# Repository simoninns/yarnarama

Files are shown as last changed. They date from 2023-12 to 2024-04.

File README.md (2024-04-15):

# Yarnarama - A yarn holder for knitting
## Overview
Yaranarama is a yarn holder for the discerning knitting engineer.  It features a fully bearing supported wool spindle mounted on a weighted based, as well as a built-in yarn guide.

This project is GPLv3 open-source and was designed with the assistance my daughter who is an enthusiastic knitter.

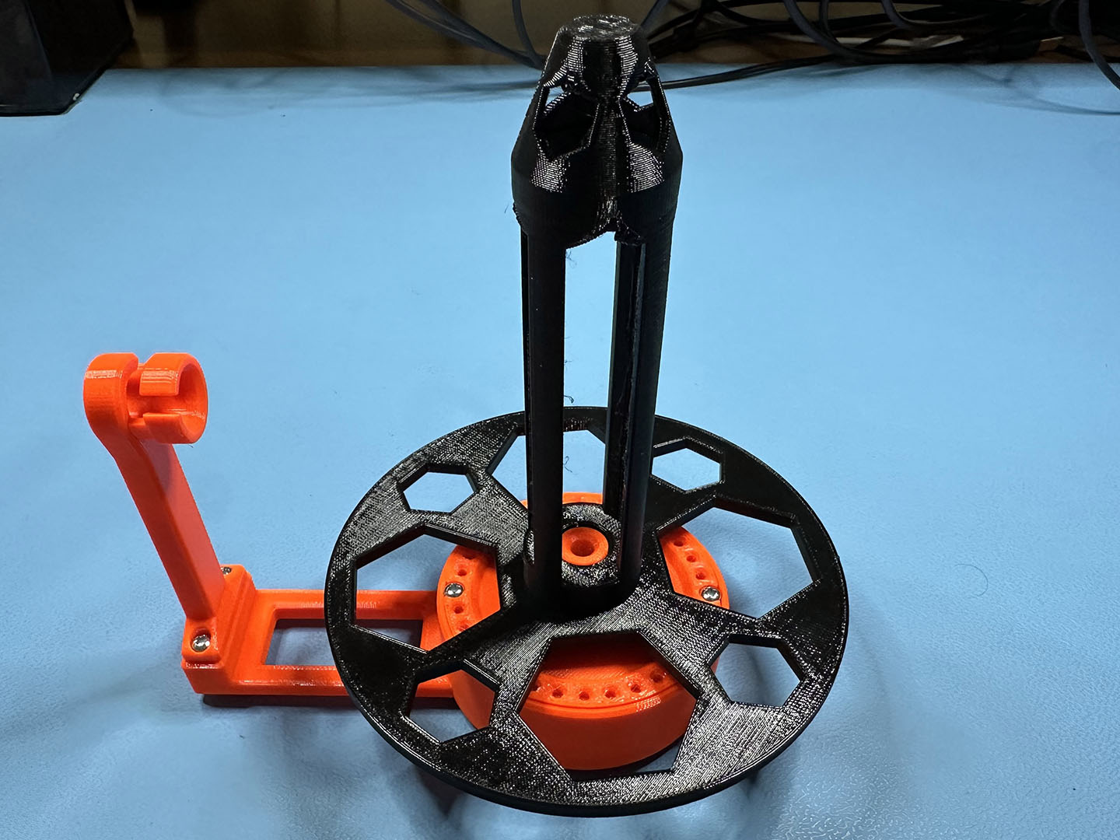
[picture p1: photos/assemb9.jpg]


## Printing instructions
The model has been printed and tested on the Prusa MK3S/MMU2S printer using Prusament PETG filament. All parts fit the standard print bed.

You will need:

* 5x M3x5.7 threaded inserts (heat-set)
* 5x M3x10mm screws
* 1x 608-2Z ball bearing
* 5x M20 washers (DIN9021 - id=22, od=60, h=3.5).
* 5x 13mm stick-on feet

When mounting the washers in the base it is advisable to pad any gap at the top of the bearings to stop them moving around.  Some foam tape or small bits of loose foam will work well.

### Recommended print settings

Print settings (for Prusa Slicer) are the same for all included parts:

* Material: PETG
* Layer: 0.30mm (Draft)
* Infill: 25%
* No supports required

Note: 0.30mm is used for fast print speed.  You can also use 0.20mm (Quality) if you like smoother looking prints.

## Assembly

Print all the parts.  Note that there are two types of shafts included, the standard diameter and a narrow shaft (to allow the yarn to relax slightly more).

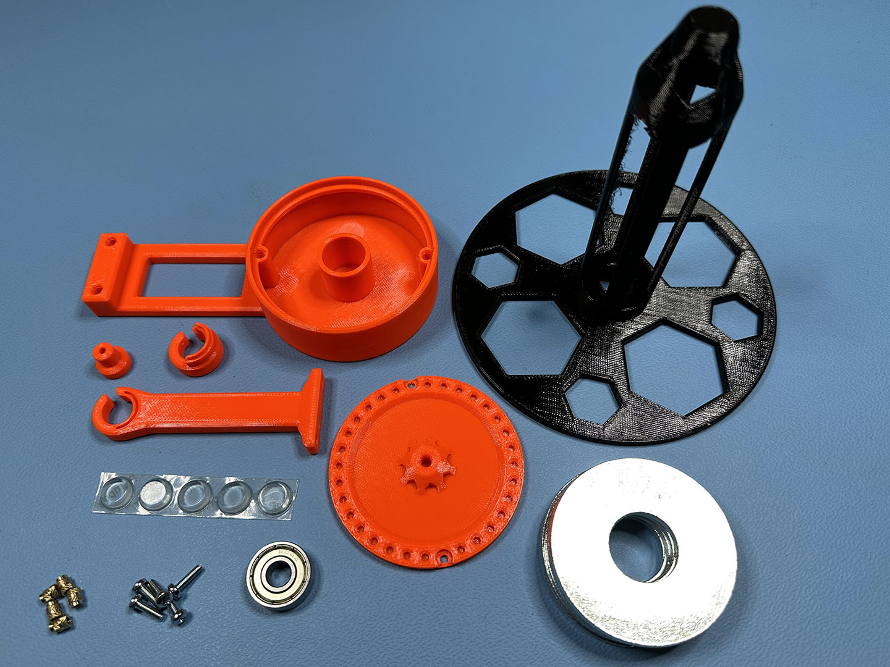
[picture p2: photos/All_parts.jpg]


Insert the heat set inserts in the base (4x) and spool base (1x).

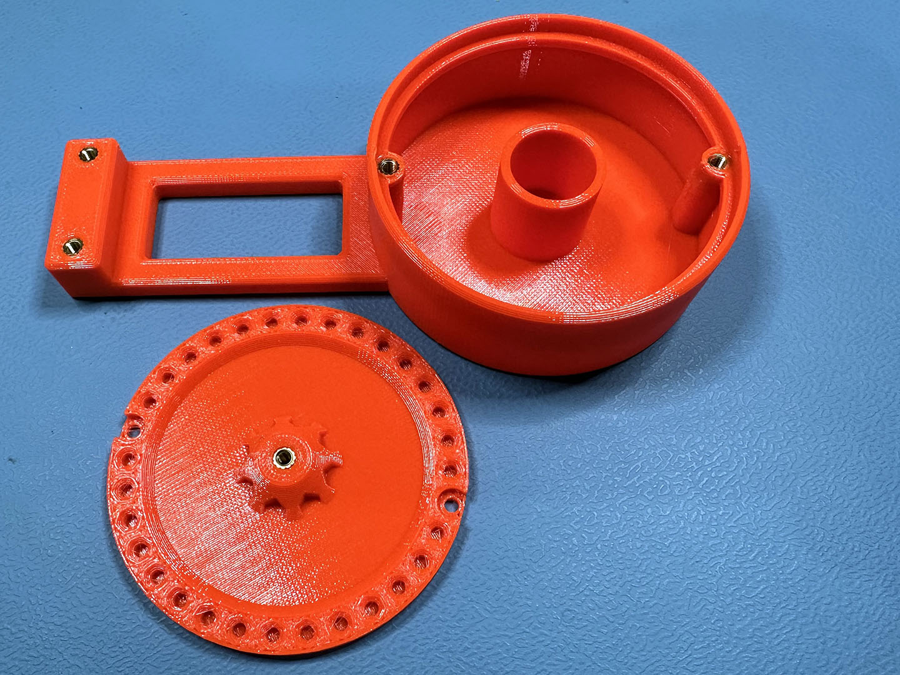
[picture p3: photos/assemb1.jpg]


Stick the 5 13mm feet to the base of the Yarnarama

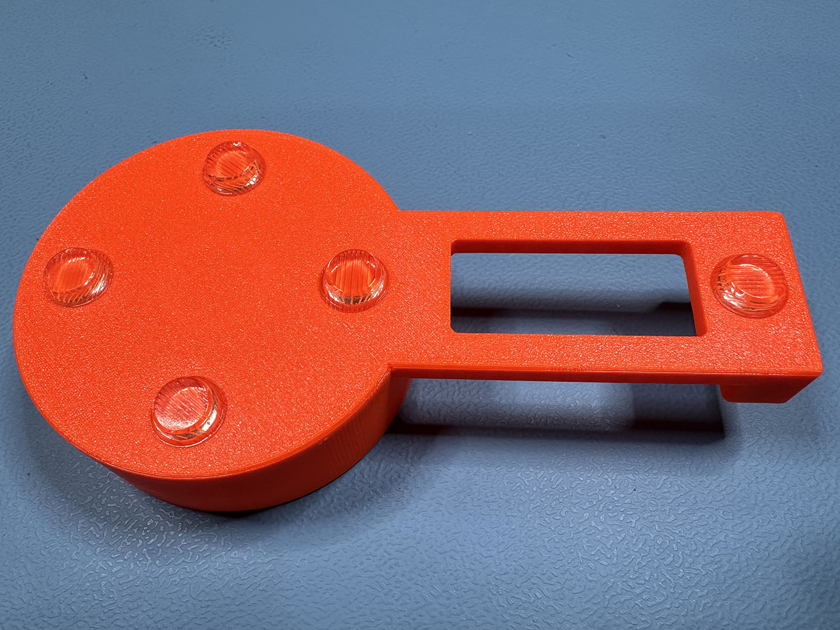
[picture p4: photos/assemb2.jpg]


Place 5 washers into the base, add some foam to the top washer to stop it moving when assembled.

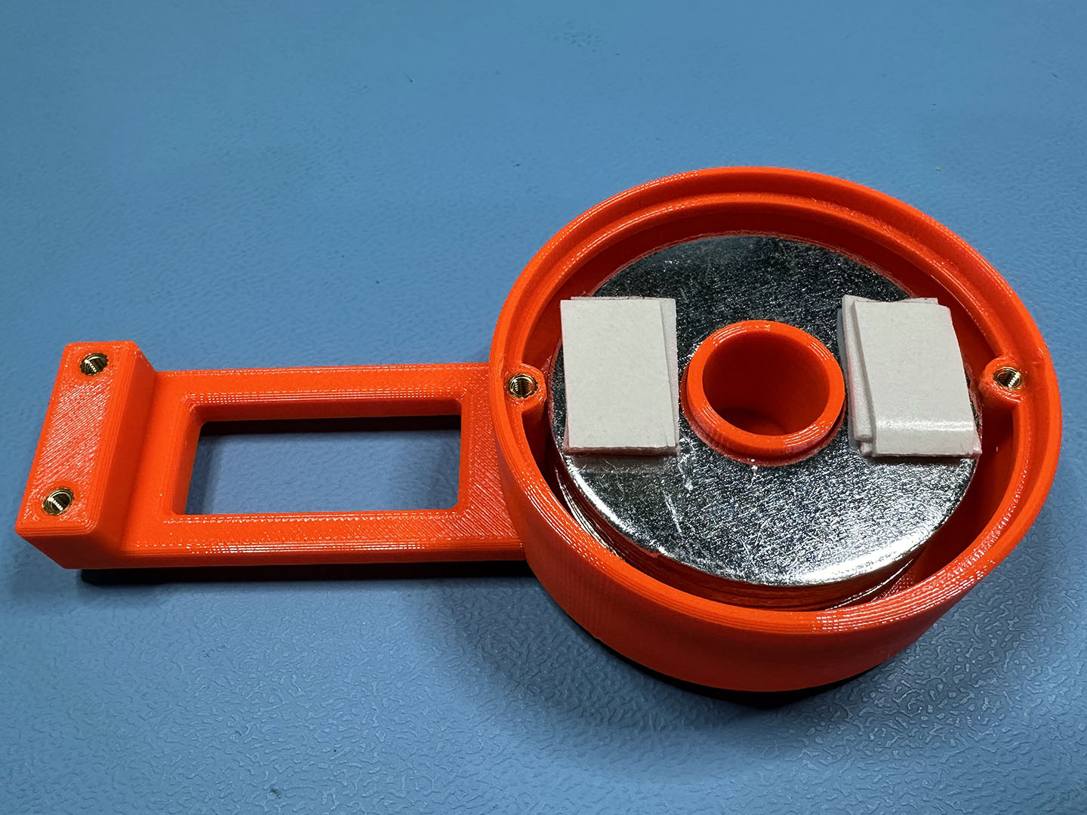
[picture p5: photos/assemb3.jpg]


Screw the spool base into place using 2x M3x10mm screws and put 1x M3x10mm screw into the spool holder

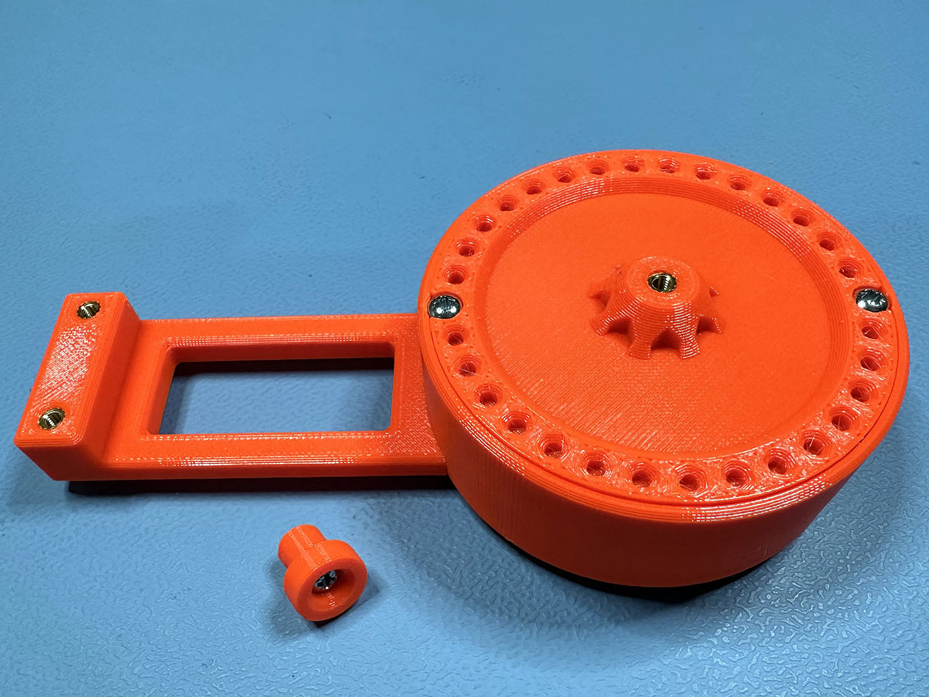
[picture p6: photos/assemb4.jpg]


Glue the guide rail into the provided slot of the guide (using a small amount of superglue)

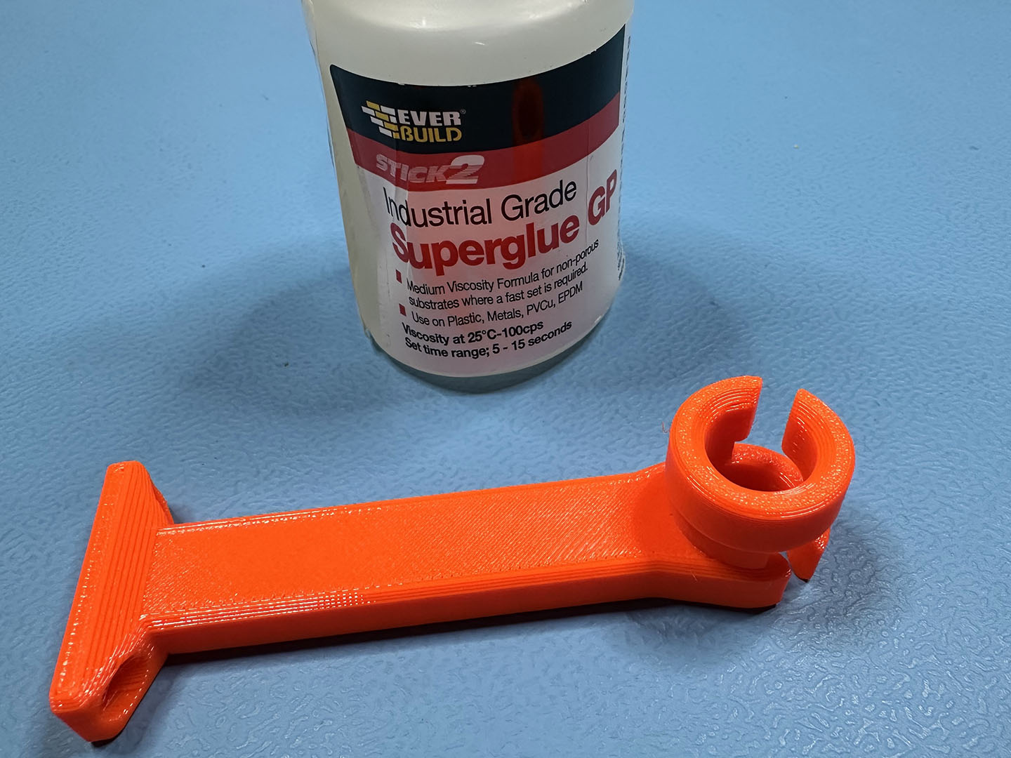
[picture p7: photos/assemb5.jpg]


Screw the guide into the base using 2x M3x10mm screws.

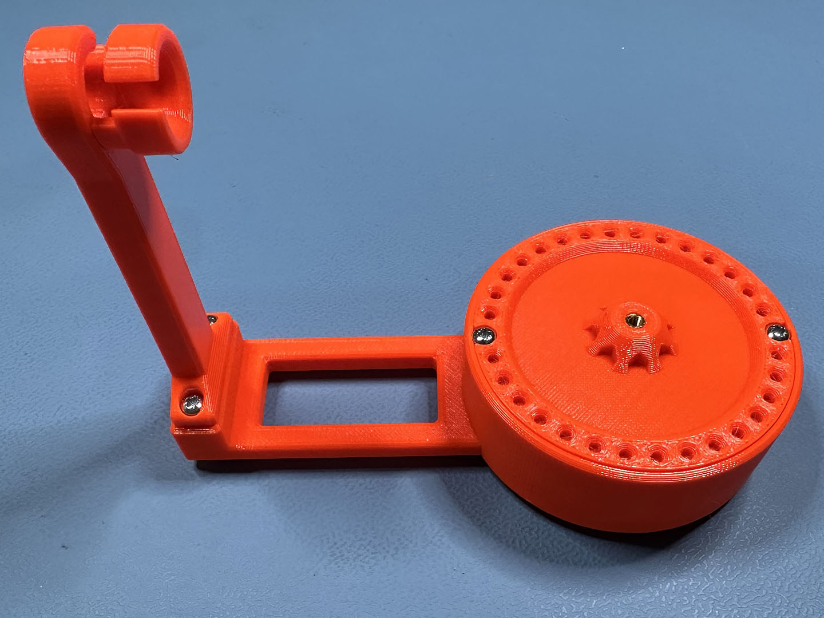
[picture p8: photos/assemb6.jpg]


Push the spool holder through the bearing

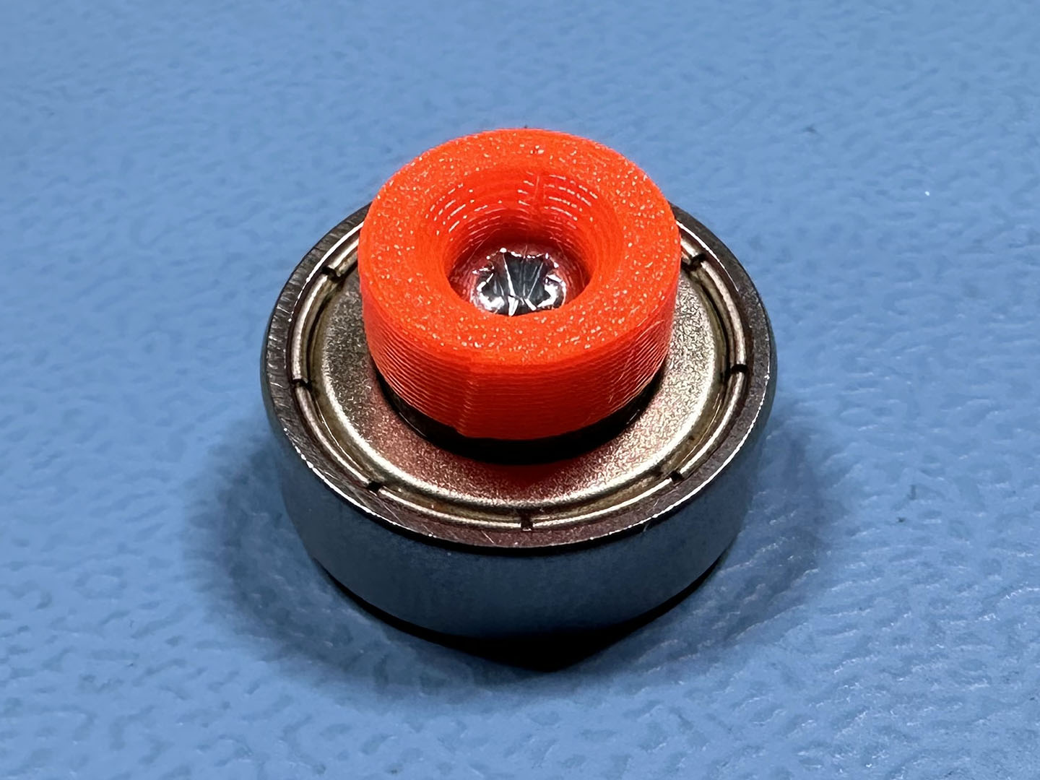
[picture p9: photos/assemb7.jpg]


Push the bearing into the base of the spool shaft

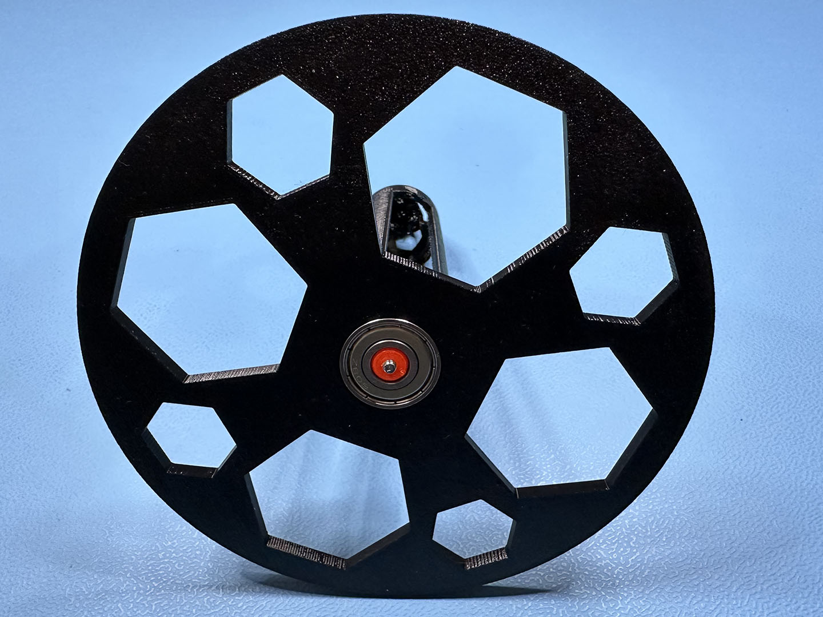
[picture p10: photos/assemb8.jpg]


Place the spool shaft onto the spool base and screw into place using the central M3x10mm screw (in the bearing holder)



## Author
The Yanarama is designed and maintained by Simon Inns.

## Cloning notes
This repo contains the BOSL OpenSCAD library as a sub-module, after you clone this repo use the following command to initialise the sub-modules:

git submodule update --init

# Licensing
## OpenSCAD source files - software license (GPLv3)

    This is free software: you can redistribute it and/or modify
    it under the terms of the GNU General Public License as published by
    the Free Software Foundation, either version 3 of the License, or
    (at your option) any later version.
    
    This program is distributed in the hope that it will be useful,
    but WITHOUT ANY WARRANTY; without even the implied warranty of
    MERCHANTABILITY or FITNESS FOR A PARTICULAR PURPOSE.  See the
    GNU General Public License for more details.
    
    You should have received a copy of the GNU General Public License
    along with this program.  If not, see <http://www.gnu.org/licenses/>.

## Non-source-code media - Creative Commons license (Creative Commons BY-SA 4.0)
Please see the following link for details: https://creativecommons.org/licenses/by-sa/4.0/

You are free to:

Share - copy and redistribute the material in any medium or format
Adapt - remix, transform, and build upon the material
for any purpose, even commercially.

This license is acceptable for Free Cultural Works.

The licensor cannot revoke these freedoms as long as you follow the license terms.

Under the following terms:

Attribution - You must give appropriate credit, provide a link to the license, and indicate if changes were made. You may do so in any reasonable manner, but not in any way that suggests the licensor endorses you or your use.

ShareAlike - If you remix, transform, or build upon the material, you must distribute your contributions under the same license as the original.

No additional restrictions - You may not apply legal terms or technological measures that legally restrict others from doing anything the license permits.

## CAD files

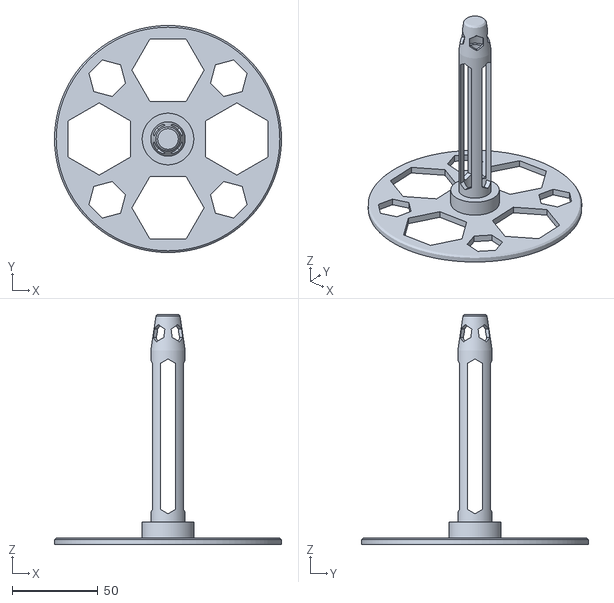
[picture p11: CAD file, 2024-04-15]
stl/spool_shaft_narrow.stl
132.0 x 132.0 x 134.0

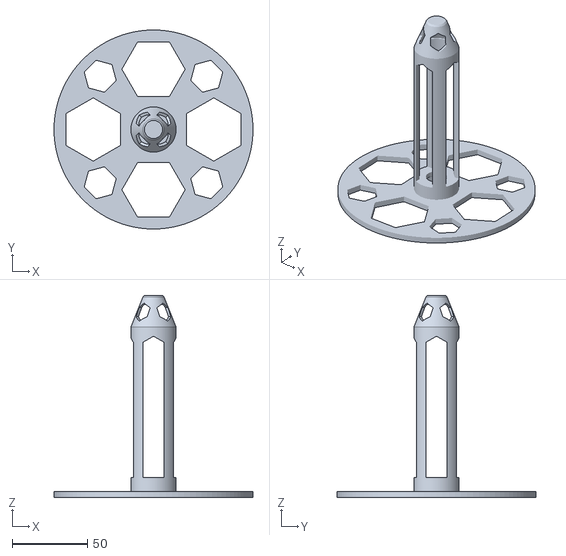
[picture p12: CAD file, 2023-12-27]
stl/spool_shaft.stl
132.0 x 132.0 x 134.0

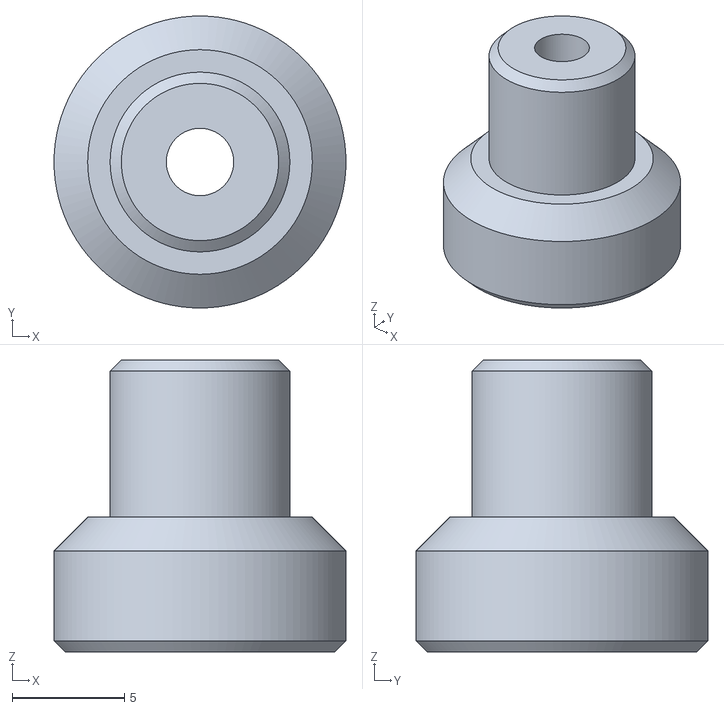
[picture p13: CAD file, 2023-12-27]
stl/bearing_holder.stl
13.0 x 13.0 x 13.0

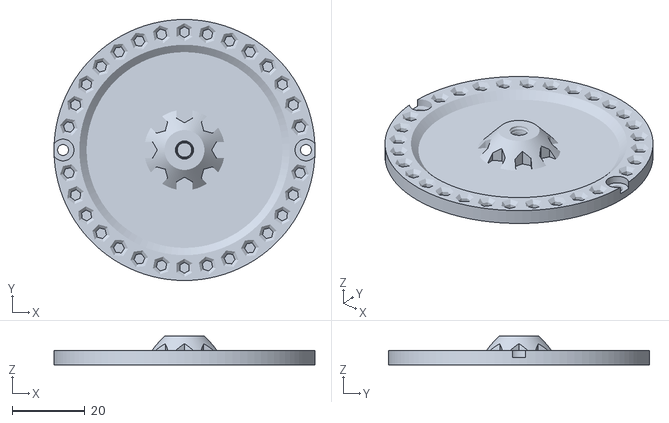
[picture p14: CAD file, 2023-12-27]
stl/spool_base.stl
72.0 x 72.0 x 8.00

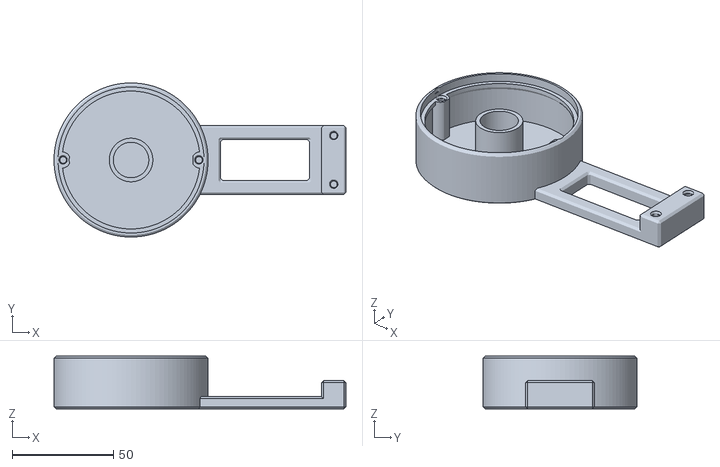
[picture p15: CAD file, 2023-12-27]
stl/base.stl
144.0 x 76.0 x 26.0

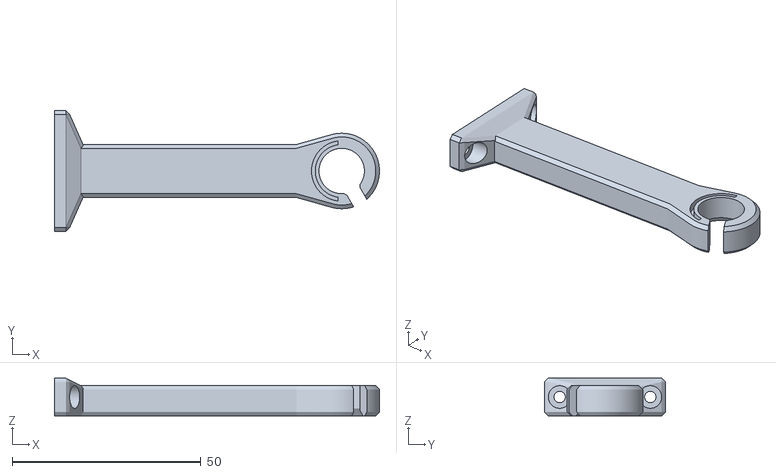
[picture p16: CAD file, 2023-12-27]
stl/guide.stl
86.0 x 32.0 x 10.0

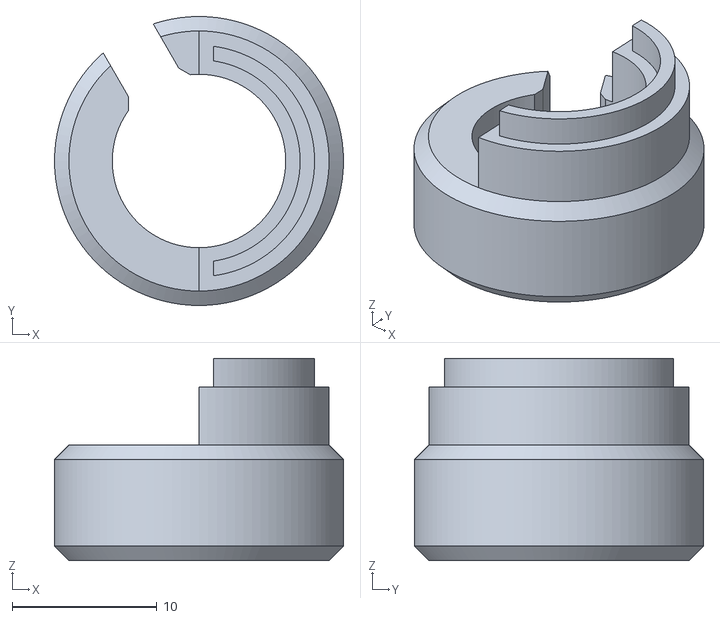
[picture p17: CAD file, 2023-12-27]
stl/guide_rail.stl
20.0 x 20.0 x 14.0

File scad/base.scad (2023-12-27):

/************************************************************************

    base.scad
    
    Yarnarama - A yarn holder for knitting
    Copyright (C) 2023 Simon Inns
    
    This is free software: you can redistribute it and/or modify
    it under the terms of the GNU General Public License as published by
    the Free Software Foundation, either version 3 of the License, or
    (at your option) any later version.
    
    This program is distributed in the hope that it will be useful,
    but WITHOUT ANY WARRANTY; without even the implied warranty of
    MERCHANTABILITY or FITNESS FOR A PARTICULAR PURPOSE.  See the
    GNU General Public License for more details.
    
    You should have received a copy of the GNU General Public License
    along with this program.  If not, see <http://www.gnu.org/licenses/>.
	
    Email: simon.inns@gmail.com
    
************************************************************************/

include <BOSL/constants.scad>
use <BOSL/transforms.scad>
use <BOSL/shapes.scad>

include <threaded_inserts.scad>

module base()
{
    difference() {
        move([0,0,-6]) cyl(h=26, d=80 - 4, chamfer=1);
        move([0,0,2]) cyl(h=38, d=80 - 8);

        // 3M 13mm bumpons
        move([0,0,-14 - 5.5]) {
            rotate([0,0,0]) move([26,0,0]) cyl(h=2,d=13);
            rotate([0,0,90]) move([26,0,0]) cyl(h=2,d=13);
            rotate([0,0,180]) move([26,0,0]) cyl(h=2,d=13);
            rotate([0,0,270]) move([26,0,0]) cyl(h=2,d=13);
        }

        // M3 Screw recess
        move([33.5,0,8]) cyl(h=6,d=6);
        move([-33.5,0,8]) cyl(h=6,d=6);
    } 

    // Add Washer holding hub
    move([0,0,-3 - 4]) difference() {
        cyl(h=20,d=21.5);
        cyl(h=22,d=21.5 - 4);
    }

    // Rim with screw mounts
    difference() {
        union() {
            // Add rim for spool base to attach to
            move([0,0, 10 - 5 - 4]) {
                difference() {
                    cyl(h=4, d=80-8);
                    cyl(h=8, d=80-8-4);
                    move([0,0,-1]) cyl(h=2.1, d1=80-8, d2=80-8-4);
                }
            }

            // Screw mounts
            move([34,0,-3 - 4]) cyl(h=20,d=8);
            move([-34,0,-3 - 4]) cyl(h=20,d=8);
        }

        // Clearance for washers
        move([0,0,2]) cyl(h=38, d=61);

        // Holes for threaded inserts
        move([33.5,0,-2]) cyl(h=12,d=5);
        move([-33.5,0,-2]) cyl(h=12,d=5);
    }

    // Inserts
    move([33.5,0,3]) insertM3x57_th();
    move([-33.5,0,3]) insertM3x57_th();

    // Guide arm
    difference() {
        union() {
            difference() {
                union() {
                    move([69,0,-16]) cuboid([74,34,6], chamfer=1);
                    move([100,0,-10]) cuboid([12,34,10], chamfer=1);
                }
                move([66,0,-16]) cuboid([74-30,34-14,10], chamfer=1);
                move([66,0,-9]) cuboid([74-30 + 2,34-14 + 2,10], chamfer=1);
                move([0,0,2]) cyl(h=38, d=80 - 8);
            }
        }

        // 3M 13mm bumpons
        move([0,0,-14 - 5.5]) {
            rotate([0,0,0]) move([28 + 68.5,0,0]) cyl(h=2,d=13);
        }

        // Guide attachment holes for threaded inserts
        move([100,12,-10]) cyl(h=11,d=5);
        move([100,-12,-10]) cyl(h=11,d=5);
    }

    // Guide attachment inserts
    move([100,12,-5]) insertM3x57_th();
    move([100,-12,-5]) insertM3x57_th();
}

module render_base(toPrint, open) {
    if (!toPrint) {
        move([0,0,19]) base();
    } else {
        move([0,0,19]) base();
    }
}

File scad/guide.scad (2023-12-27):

/************************************************************************

    guide.scad
    
    Yarnarama - A yarn holder for knitting
    Copyright (C) 2023 Simon Inns
    
    This is free software: you can redistribute it and/or modify
    it under the terms of the GNU General Public License as published by
    the Free Software Foundation, either version 3 of the License, or
    (at your option) any later version.
    
    This program is distributed in the hope that it will be useful,
    but WITHOUT ANY WARRANTY; without even the implied warranty of
    MERCHANTABILITY or FITNESS FOR A PARTICULAR PURPOSE.  See the
    GNU General Public License for more details.
    
    You should have received a copy of the GNU General Public License
    along with this program.  If not, see <http://www.gnu.org/licenses/>.
	
    Email: simon.inns@gmail.com
    
************************************************************************/

include <BOSL/constants.scad>
use <BOSL/transforms.scad>
use <BOSL/shapes.scad>

module guide_rail()
{
    move([99,0,90]) {
        difference() {
            union() {
                move([-12,0,0]) yrot(90) cyl(h=8,d=20, chamfer=1);
                //move([-6,0,0]) yrot(90) cyl(h=4,d=18);
            }
            move([-12,0,0]) yrot(90) cyl(h=20,d=12);

            // Slice
            xrot(-60) move([-12,0,8]) {
                cuboid([14,4,8]);
                move([0,1,-2]) xrot(30) cuboid([15,2,4]);
                move([0,-1,-2]) xrot(-30) cuboid([15,2,4]);
            }
            
            // Smooth the middle
            move([-17,0,0]) yrot(90) cyl(h=10,d=16, chamfer=4);  
        }

        // Centre part
        difference() {
            move([-6,0,0]) yrot(90) cyl(h=4,d=18);
            move([-6,0,10]) cuboid([20,20,20]);
            move([-12,0,0]) yrot(90) cyl(h=20,d=12);
        }

        // Centre joiner
        difference() {
            move([-4,0,0]) yrot(90) cyl(h=4,d=16);
            move([-4,0,9]) cuboid([20,20,20]);
            move([-10,0,0]) yrot(90) cyl(h=20,d=14);
        }
    }
}

module guide_top()
{
    move([99,0,90]) {
        
        difference() {
            union() {
                hull() {
                    move([0,0,-11]) cuboid([8,14,2], chamfer=1, edges=EDGES_Z_ALL);
                    yrot(90) cyl(h=8,d=20, chamfer=1);
                }
            }

            move([-3,0,0]) yrot(90) cyl(h=20,d=12);

            // Slice
            xrot(60) move([0,0,8]) {
                cuboid([14,4,8]);
                move([0,1,-2]) xrot(30) cuboid([15,2,4]);
                move([0,-1,-2]) xrot(-30) cuboid([15,2,4]);
            }

            // Smooth the middle
            move([5,0,0]) yrot(90) cyl(h=10,d=16, chamfer=4);

            // Centre joiner
            difference() {
                move([-4,0,0]) yrot(90) cyl(h=4,d=16);
                move([-4,0,9]) cuboid([20,20,20]);
                move([-10,0,0]) yrot(90) cyl(h=20,d=14);
            }
        }
    }
}

module guide()
{
    move([100,0,100-6]) {
        // Shaft
        move([-1,0,-45]) cuboid([8,14,58], chamfer=1, edges=EDGES_ALL-EDGES_TOP);

        // Flared base
        difference() {
            hull() {
                move([-1,0,-74]) cuboid([8,14,4], chamfer=1);
                move([-2,0,-78]) cuboid([10,32,4], chamfer=1, edges=EDGES_ALL-EDGES_BOTTOM);
            }

            // Screw holes
            move([-2,0,0]) {
                move([0,12,10-94]) cyl(h=40,d=3);
                move([0,-12,10-94]) cyl(h=40,d=3);

                move([0,12,26-94]) cyl(h=20,d=6);
                move([0,-12,26-94]) cyl(h=20,d=6);
            }
        }
    }
}

module render_guide(toPrint, open) {
    if (!toPrint) {
        move([2,0,0]) {
            guide();
            guide_top();
        }
    } else {
        move([-60,0,103]) yrot(90) {
            guide();
            guide_top();
        }
    }
}

module render_guide_rail(toPrint, open) {
    if (!toPrint) {
        move([2,0,0]) {
            guide_rail();
        }
    } else {
        move([90,0,-83]){
            yrot(-90) guide_rail();
        }
    }
}

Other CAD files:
scad/bearing.scad
scad/main.scad
scad/spool_base.scad
scad/spool_shaft.scad
scad/spool_shaft_narrow.scad
scad/threaded_inserts.scad
scad/washers.scad

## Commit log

2023-12-27 Transfering project to public github repo
    [base.scad, base.stl, bearing.scad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]
2023-12-28 Updated readme with assembly photos
2024-04-15 Added a narrow version of the shaft including STL and a short update to the readme file.
    [main.scad, spool_shaft_narrow.scad, spool_shaft_narrow.stl]
